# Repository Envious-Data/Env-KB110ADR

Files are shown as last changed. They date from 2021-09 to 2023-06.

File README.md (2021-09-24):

# Env-KB110ADR
A STM32F411CEU6 powered Mechanical keyboard PCB designed in KiCad

- Project Name: Env-KB110ADR
- Nickname: Victus

### About
I originally helped a friend design this but he couldnt quite figure out kicad nor had the motivation, It started out as a RP2040 powered 110% layout and then got cut down to a normal 100% and switched to a STM32F411CEU6.

It also support hotswap and ansi+iso.

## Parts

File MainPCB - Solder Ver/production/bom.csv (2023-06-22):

Designator | Footprint | Quantity | Value | LCSC Part #
C9 | 0805 | 1 | 0.1uf 0805
D_100, D_101, D_102, D_103, D_104, D_105, D_106, D_107, D_108, D_109, D_110, D_111, D_112, D_113, D_114, D_115, D_116, D_117, D_12, D_13, D_14, D_15, D_16, D_17, D_18, D_19, D_20, D_21, D_22, D_23, D_24, D_25, D_26, D_27, D_28, D_29, D_30, D_31, D_32, D_33, D_34, D_35, D_36, D_37, D_38, D_39, D_40, D_41, D_42, D_43, D_44, D_45, D_46, D_47, D_48, D_49, D_50, D_51, D_52, D_53, D_54, D_55, D_56, D_57, D_58, D_59, D_60, D_61, D_62, D_63, D_64, D_65, D_66, D_67, D_68, D_69, D_70, D_71, D_72, D_73, D_74, D_75, D_76, D_77, D_78, D_79, D_80, D_81, D_82, D_83, D_84, D_85, D_86, D_87, D_88, D_89, D_90, D_91, D_92, D_93, D_94, D_95, D_96, D_97, D_98, D_99 | D_SOD-123 | 106 | 1N4148W
H1, H10, H11, H12, H2, H3, H4, H5, H6, H7, H8, H9 | MountingHole_2.2mm_M2_Pad-Mod | 12 | MountingHole
J5 | PinHeader_1x03_P1.00mm_Vertical | 1 | Conn_01x03_Male
K_100, K_101, K_102, K_103, K_104, K_104B1, K_105, K_105B1, K_106, K_106B1, K_107, K_107B1, K_108, K_108C1, K_109, K_110, K_111, K_112, K_113, K_114, K_115, K_116, K_12, K_13, K_14, K_15, K_16, K_17, K_18, K_19, K_20, K_21, K_22, K_23, K_24, K_25, K_26, K_27, K_28, K_29, K_30, K_31, K_32, K_33, K_34, K_35, K_36, K_37, K_38, K_39, K_40, K_41, K_42, K_43, K_44, K_45, K_46, K_47, K_48, K_49, K_50, K_51, K_52, K_53, K_54, K_55, K_56, K_57, K_58, K_59, K_60, K_61, K_62, K_63, K_64, K_65, K_66, K_67, K_68, K_69, K_70, K_70B1, K_71, K_72, K_73, K_74, K_75, K_76, K_77, K_78, K_79, K_80, K_81, K_82, K_83, K_84, K_85, K_86, K_87, K_88, K_89, K_90, K_91, K_92, K_93, K_94, K_95, K_96, K_97, K_98, K_99, K_ANSI_1, K_ANSI_2, K_ANSI_3 | MXOnly-1U-NoLED | 114 | KEYSW
R5, R6 | 0805 | 2 | 5.1K 0805
R8 | 0805 | 1 | 330r 0805
SW1, SW2 | Panasonic_EVQPUL_EVQPUC | 2 | EVQP
U2 | PGA2040 | 1 | PGA2040
USB1 | USB_C_TYPE-C-31-M-14 | 1 | TYPE-C-31-M-14 | C319148
stab1, stab2, stab3, stab4, stab6, stab7, stab8, stab9 | Stabilizer_Cherry_MX_2u | 8 | MountingHole
stab101 | Stabilizer_Cherry_MX_7u | 1 | MountingHole
stab5 | Stabilizer_Cherry_MX_6.25u | 1 | MountingHole

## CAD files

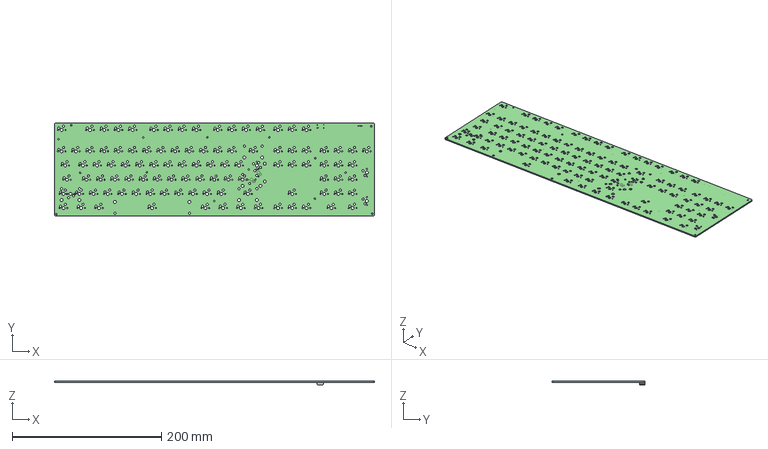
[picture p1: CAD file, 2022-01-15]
MainPCB-RP2040/EnvKB110ADR-RP2040.step
429.5 x 125.0 x 4.86 mm
EnvKB110ADR-RP2040 PCB

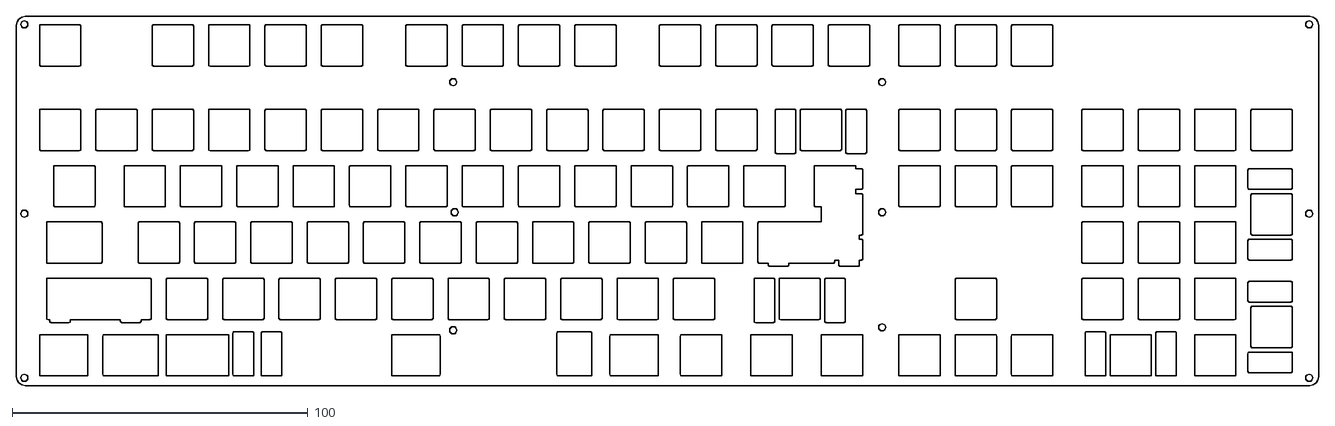
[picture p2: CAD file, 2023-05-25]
SwitchPlate/_gbr/110ADR-SwitchPlate-Edge_Cuts.dxf
440.3 x 124.8

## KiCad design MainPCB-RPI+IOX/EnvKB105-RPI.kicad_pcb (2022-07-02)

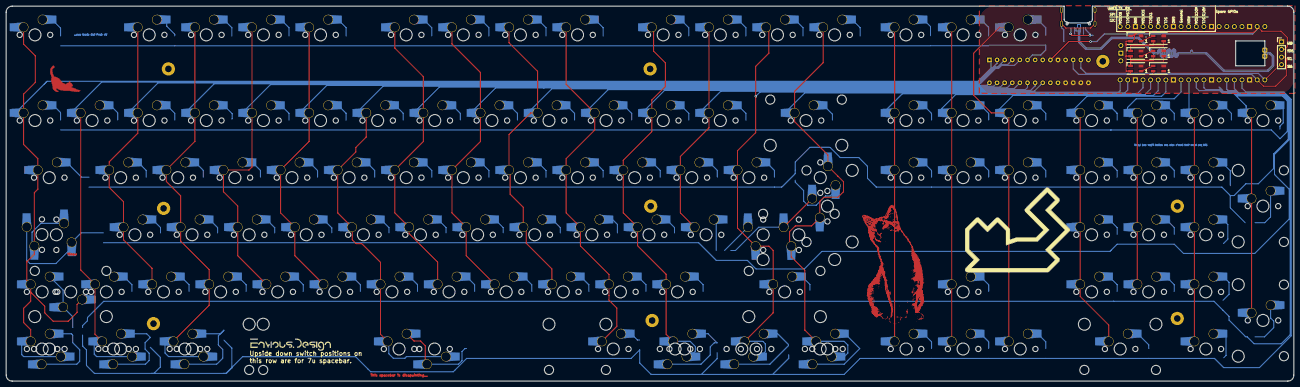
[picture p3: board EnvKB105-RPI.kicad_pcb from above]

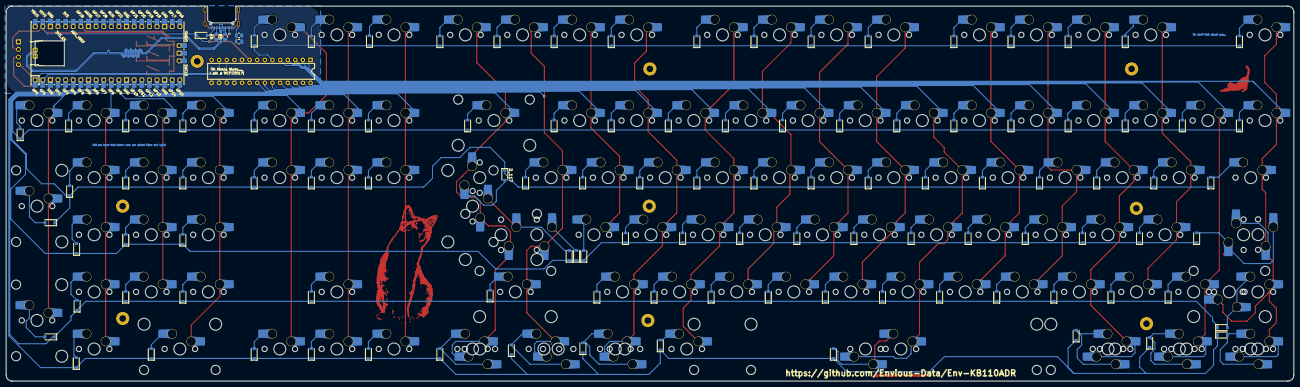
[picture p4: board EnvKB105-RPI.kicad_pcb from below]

Board: 2 copper layers, 429.5 x 125.1 mm, 257 parts (114 on the bottom side), 150 nets.

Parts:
C1: 0.1uf; C_0805_2012Metric
D1: 1N4002W; D_SOD-123
D_12, D_13, D_14, D_15, D_16, D_17, D_18, D_19, D_20, D_21, D_22, D_23, D_24, D_25, D_26, D_27, D_28, D_29, D_30, D_31, D_32, D_33, D_34, D_35, D_36, D_37, D_38, D_39, D_40, D_41, D_42, D_43, D_44, D_45, D_46, D_47, D_48, D_49, D_50, D_51, D_52, D_53, D_54, D_55, D_56, D_57, D_58, D_59, D_60, D_61, D_62, D_63, D_64, D_65, D_66, D_67, D_68, D_69, D_70, D_71, D_72, D_73, D_74, D_75, D_76, D_77, D_78, D_79, D_80, D_81, D_82, D_83, D_84, D_85, D_86, D_87, D_88, D_89, D_90, D_91, D_92, D_93, D_94, D_95, D_96, D_97, D_98, D_99, D_100, D_101, D_102, D_103, D_104, D_105, D_106, D_107, D_108, D_109, D_110, D_111, D_112, D_113, D_114, D_115, D_116, D_117: SOD-123; D_SOD-123
H1, H2, H3, H4, H5, H6, H7, H8, H9: MountingHole; MountingHole_2.2mm_M2_Pad-Mod
J1: Conn_01x04; PinHeader_1x04_P2.54mm_Vertical
K_12, K_13, K_14, K_15, K_16, K_17, K_18, K_19, K_20, K_21, K_22, K_23, K_24, K_25, K_26, K_27, K_28, K_29, K_30, K_31, K_32, K_33, K_34, K_35, K_36, K_37, K_38, K_39, K_40, K_41, K_42, K_43, K_44, K_45, K_46, K_47, K_48, K_49, K_50, K_51, K_52, K_53, K_54, K_55, K_56, K_57, K_58, K_59, K_60, K_61, K_62, K_63, K_64, K_65, K_66, K_67, K_68, K_69, K_70, K_70B1, K_71, K_72, K_73, K_74, K_75, K_76, K_77, K_78, K_79, K_80, K_81, K_82, K_83, K_84, K_85, K_86, K_87, K_88, K_89, K_90, K_91, K_92, K_93, K_94, K_95, K_96, K_97, K_98, K_99, K_100, K_101, K_102, K_103, K_104, K_104B1, K_105, K_105B1, K_106, K_106B1, K_107, K_107B1, K_108, K_108B1, K_109, K_109B1, K_110, K_111, K_111B1, K_112, K_113, K_114, K_115, K_116: KEYSW; MXOnly-1U-Hotswap-Modified
K_ANSI_1, K_ANSI_2, K_ANSI_3: KEYSW; MXOnly-1U-Hotswap-Modified
R1: 330r; R_0805_2012Metric
R5, R6: 5.1K 0402; R_0805_2012Metric
U1: Pico; RPi_Pico_SMD_TH_Modified
U2: MCP23017_SP; DIP-28_W7.62mm
USB1: TYPE-C-31-M-14; USB_C_TYPE-C-31-M-14
kibuzzard-6261CED5: G***; kibuzzard-6261CED5
rgb1, rgb2, rgb3, rgb4, rgb5, rgb6: SK6812MINI; LED_SK6812MINI_PLCC4_3.5x3.5mm_P1.75mm
stab1, stab2, stab3, stab4, stab6, stab7, stab8, stab9: MountingHole; Stabilizer_Cherry_MX_2u
stab5: MountingHole; Stabilizer_Cherry_MX_6.25u
stab101: MountingHole; Stabilizer_Cherry_MX_7u

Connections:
GND: C1.2, J1.1, R1.2, R5.1, R6.1, U1.3 (GND), U1.8 (GND), U1.13 (GND), U1.18 (GND), U1.23 (GND), U1.28 (GND), U1.33 (AGND), U1.38 (GND), U2.10 (VSS), U2.15 (A0), U2.16 (A1), U2.17 (A2), U2.18 (~RESET), USB1.A1 (GND), USB1.A12 (GND), USB1.B1 (GND), USB1.B12 (GND), rgb1.2 (VSS), rgb2.2 (VSS), rgb3.2 (VSS), rgb4.2 (VSS), rgb5.2 (VSS), rgb6.2 (VSS)
GP28-LED: U1.34 (GPIO28_ADC2), rgb1.3 (DIN)
I2C_SCL-1: J1.3, U1.2 (GPIO1), U2.12 (SCK)
I2C_SDA-1: J1.4, U1.1 (GPIO0), U2.13 (SDA)
unnamed: C1.1, R1.1, USB1.S1 (SHIELD)
unnamed: D_12.2 (A), K_12.2 (ROW)
unnamed: D_13.2 (A), K_13.2 (ROW)
unnamed: D_14.2 (A), K_14.2 (ROW)
unnamed: D_15.2 (A), K_15.2 (ROW)
unnamed: D_16.2 (A), K_16.2 (ROW)
unnamed: D_17.2 (A), K_17.2 (ROW)
unnamed: D_18.2 (A), K_18.2 (ROW)
unnamed: D_19.2 (A), K_19.2 (ROW)
unnamed: D_20.2 (A), K_20.2 (ROW)
unnamed: D_21.2 (A), K_21.2 (ROW)
unnamed: D_22.2 (A), K_22.2 (ROW)
unnamed: D_23.2 (A), K_23.2 (ROW)
unnamed: D_24.2 (A), K_24.2 (ROW)
unnamed: D_25.2 (A), K_25.2 (ROW)
unnamed: D_26.2 (A), K_26.2 (ROW)
unnamed: D_27.2 (A), K_27.2 (ROW)
unnamed: D_28.2 (A), K_28.2 (ROW)
unnamed: D_29.2 (A), K_29.2 (ROW)
unnamed: D_30.2 (A), K_30.2 (ROW)
unnamed: D_31.2 (A), K_31.2 (ROW)
unnamed: D_32.2 (A), K_32.2 (ROW)
unnamed: D_33.2 (A), K_33.2 (ROW)
unnamed: D_34.2 (A), K_34.2 (ROW)
unnamed: D_35.2 (A), K_35.2 (ROW)
unnamed: D_36.2 (A), K_36.2 (ROW)
unnamed: D_37.2 (A), K_37.2 (ROW)
unnamed: D_38.2 (A), K_38.2 (ROW)
unnamed: D_39.2 (A), K_39.2 (ROW)
unnamed: D_40.2 (A), K_40.2 (ROW)
unnamed: D_41.2 (A), K_41.2 (ROW)
unnamed: D_42.2 (A), K_42.2 (ROW)
unnamed: D_43.2 (A), K_43.2 (ROW)
unnamed: D_44.2 (A), K_44.2 (ROW)
unnamed: D_45.2 (A), K_45.2 (ROW)
unnamed: D_46.2 (A), K_46.2 (ROW)
unnamed: D_47.2 (A), K_47.2 (ROW)
unnamed: D_48.2 (A), K_48.2 (ROW)
unnamed: D_49.2 (A), K_49.2 (ROW)
unnamed: D_50.2 (A), K_50.2 (ROW)
unnamed: D_51.2 (A), K_51.2 (ROW)
unnamed: D_52.2 (A), K_52.2 (ROW)
unnamed: D_53.2 (A), K_53.2 (ROW)
unnamed: D_54.2 (A), K_54.2 (ROW)
unnamed: D_55.2 (A), K_55.2 (ROW)
unnamed: D_56.2 (A), K_56.2 (ROW)
unnamed: D_57.2 (A), K_57.2 (ROW)
unnamed: D_58.2 (A), K_58.2 (ROW)
unnamed: D_59.2 (A), K_59.2 (ROW)
unnamed: D_60.2 (A), K_60.2 (ROW)
unnamed: D_61.2 (A), K_61.2 (ROW)
unnamed: D_62.2 (A), K_62.2 (ROW), K_ANSI_2.2 (ROW)
unnamed: D_63.2 (A), K_63.2 (ROW)
unnamed: D_64.2 (A), K_64.2 (ROW)
unnamed: D_65.2 (A), K_65.2 (ROW)
unnamed: D_66.2 (A), K_66.2 (ROW)
unnamed: D_67.2 (A), K_67.2 (ROW)
unnamed: D_68.2 (A), K_68.2 (ROW)
unnamed: D_69.2 (A), K_69.2 (ROW)
unnamed: D_70.2 (A), K_70.2 (ROW), K_70B1.2 (ROW)
unnamed: D_71.2 (A), K_71.2 (ROW)
unnamed: D_72.2 (A), K_72.2 (ROW)
unnamed: D_73.2 (A), K_73.2 (ROW)
unnamed: D_74.2 (A), K_74.2 (ROW)
unnamed: D_75.2 (A), K_75.2 (ROW)
unnamed: D_76.2 (A), K_76.2 (ROW)
unnamed: D_77.2 (A), K_77.2 (ROW)
unnamed: D_78.2 (A), K_78.2 (ROW)
unnamed: D_79.2 (A), K_79.2 (ROW)
unnamed: D_80.2 (A), K_80.2 (ROW)
unnamed: D_81.2 (A), K_81.2 (ROW)
unnamed: D_82.2 (A), K_82.2 (ROW)
unnamed: D_83.2 (A), K_83.2 (ROW)
unnamed: D_84.2 (A), K_84.2 (ROW)
unnamed: D_85.2 (A), K_85.2 (ROW)
unnamed: D_86.2 (A), K_86.2 (ROW), K_ANSI_1.2 (ROW)
unnamed: D_87.2 (A), K_87.2 (ROW)
unnamed: D_88.2 (A), K_88.2 (ROW)
unnamed: D_89.2 (A), K_89.2 (ROW)
unnamed: D_90.2 (A), K_90.2 (ROW)
unnamed: D_91.2 (A), K_91.2 (ROW)
unnamed: D_92.2 (A), K_92.2 (ROW)
unnamed: D_93.2 (A), K_93.2 (ROW)
unnamed: D_94.2 (A), K_94.2 (ROW)
unnamed: D_95.2 (A), K_95.2 (ROW)
unnamed: D_96.2 (A), K_96.2 (ROW)
unnamed: D_97.2 (A), K_97.2 (ROW)
unnamed: D_98.2 (A), K_98.2 (ROW)
unnamed: D_99.2 (A), K_99.2 (ROW)
unnamed: D_100.2 (A), K_100.2 (ROW)
unnamed: D_101.2 (A), K_101.2 (ROW)
unnamed: D_102.2 (A), K_102.2 (ROW)
unnamed: D_103.2 (A), K_103.2 (ROW)
unnamed: D_104.2 (A), K_104.2 (ROW), K_104B1.2 (ROW)
unnamed: D_105.2 (A), K_105.2 (ROW), K_105B1.2 (ROW)
unnamed: D_106.2 (A), K_106.2 (ROW), K_106B1.2 (ROW)
unnamed: D_107.2 (A), K_107.2 (ROW), K_107B1.2 (ROW)
unnamed: D_108.2 (A), K_108.2 (ROW)
unnamed: D_109.2 (A), K_108B1.2 (ROW), K_109.2 (ROW)
unnamed: D_110.2 (A), K_109B1.2 (ROW), K_110.2 (ROW)
unnamed: D_111.2 (A), K_111.2 (ROW), K_111B1.2 (ROW)
unnamed: D_112.2 (A), K_112.2 (ROW)
unnamed: D_113.2 (A), K_113.2 (ROW)
unnamed: D_114.2 (A), K_114.2 (ROW)
unnamed: D_115.2 (A), K_115.2 (ROW)
unnamed: D_116.2 (A), K_116.2 (ROW)
unnamed: D_117.2 (A), K_ANSI_3.2 (ROW)
unnamed: R5.2, USB1.A5 (CC1)
unnamed: R6.2, USB1.B5 (CC2)
unnamed: rgb1.1 (DOUT), rgb2.3 (DIN)
unnamed: rgb2.1 (DOUT), rgb3.3 (DIN)
unnamed: rgb3.1 (DOUT), rgb4.3 (DIN)
unnamed: rgb4.1 (DOUT), rgb5.3 (DIN)
unnamed: rgb5.1 (DOUT), rgb6.3 (DIN)
USB_D+: U1.TP3 (USB_DP), USB1.A6 (D+), USB1.B6 (D+)
USB_D-: U1.TP2 (USB_DM), USB1.A7 (D-), USB1.B7 (D-)
VBUS: D1.2 (A), USB1.A4 (VBUS), USB1.A9 (VBUS), USB1.B4 (VBUS), USB1.B9 (VBUS)
VSYS: D1.1 (K), J1.2, U1.39 (VSYS), U2.9 (VDD), rgb1.4 (VDD), rgb2.4 (VDD), rgb3.4 (VDD), rgb4.4 (VDD), rgb5.4 (VDD), rgb6.4 (VDD)
col0: K_12.1 (COL), K_28.1 (COL), K_49.1 (COL), K_70.1 (COL), K_70B1.1 (COL), K_86.1 (COL), K_104.1 (COL), K_104B1.1 (COL), K_ANSI_1.1 (COL), U2.1 (GPB0)
col1: K_29.1 (COL), K_87.1 (COL), K_105.1 (COL), K_105B1.1 (COL), U2.2 (GPB1)
col2: K_13.1 (COL), K_30.1 (COL), K_50.1 (COL), K_71.1 (COL), K_88.1 (COL), U2.3 (GPB2)
col3: K_14.1 (COL), K_31.1 (COL), K_51.1 (COL), K_72.1 (COL), K_89.1 (COL), K_106.1 (COL), K_106B1.1 (COL), U2.4 (GPB3)
col4: K_15.1 (COL), K_32.1 (COL), K_52.1 (COL), K_73.1 (COL), K_90.1 (COL), U2.5 (GPB4)
col5: K_16.1 (COL), K_33.1 (COL), K_53.1 (COL), K_74.1 (COL), K_91.1 (COL), U2.28 (GPA7)
col6: K_34.1 (COL), K_54.1 (COL), K_75.1 (COL), K_92.1 (COL), K_107.1 (COL), K_107B1.1 (COL), U2.27 (GPA6)
col7: K_17.1 (COL), K_35.1 (COL), K_55.1 (COL), K_76.1 (COL), K_93.1 (COL), U2.26 (GPA5)
col8: K_18.1 (COL), K_36.1 (COL), K_56.1 (COL), K_77.1 (COL), K_94.1 (COL), U2.25 (GPA4)
col9: K_19.1 (COL), K_37.1 (COL), K_57.1 (COL), K_78.1 (COL), K_95.1 (COL), U2.24 (GPA3)
col10: K_20.1 (COL), K_38.1 (COL), K_58.1 (COL), K_79.1 (COL), K_96.1 (COL), K_108.1 (COL), U2.23 (GPA2)
col11: K_21.1 (COL), K_39.1 (COL), K_59.1 (COL), K_80.1 (COL), K_97.1 (COL), K_108B1.1 (COL), K_109.1 (COL), U2.22 (GPA1)
col12: K_22.1 (COL), K_40.1 (COL), K_60.1 (COL), K_81.1 (COL), U2.21 (GPA0)
col13: K_23.1 (COL), K_61.1 (COL), K_82.1 (COL), K_98.1 (COL), K_109B1.1 (COL), K_110.1 (COL), U1.20 (GPIO15)
col14: K_24.1 (COL), K_41.1 (COL), K_62.1 (COL), K_111.1 (COL), K_111B1.1 (COL), K_ANSI_2.1 (COL), K_ANSI_3.1 (COL), U1.19 (GPIO14)
col15: K_25.1 (COL), K_42.1 (COL), K_63.1 (COL), K_112.1 (COL), U1.17 (GPIO13)
col16: K_26.1 (COL), K_43.1 (COL), K_64.1 (COL), K_99.1 (COL), K_113.1 (COL), U1.16 (GPIO12)
col17: K_27.1 (COL), K_44.1 (COL), K_65.1 (COL), K_114.1 (COL), U1.15 (GPIO11)
col19: K_45.1 (COL), K_66.1 (COL), K_83.1 (COL), K_100.1 (COL), K_115.1 (COL), U1.14 (GPIO10)
col20: K_46.1 (COL), K_67.1 (COL), K_84.1 (COL), K_101.1 (COL), U1.12 (GPIO9)
col21: K_47.1 (COL), K_68.1 (COL), K_85.1 (COL), K_102.1 (COL), K_116.1 (COL), U1.11 (GPIO8)
col22: K_48.1 (COL), K_69.1 (COL), K_103.1 (COL), U1.10 (GPIO7)
row1: D_12.1 (K), D_13.1 (K), D_14.1 (K), D_15.1 (K), D_16.1 (K), D_17.1 (K), D_18.1 (K), D_19.1 (K), D_20.1 (K), D_21.1 (K), D_22.1 (K), D_23.1 (K), D_24.1 (K), D_25.1 (K), D_26.1 (K), D_27.1 (K), U2.6 (GPB5)
row3: D_28.1 (K), D_29.1 (K), D_30.1 (K), D_31.1 (K), D_32.1 (K), D_33.1 (K), D_34.1 (K), D_35.1 (K), D_36.1 (K), D_37.1 (K), D_38.1 (K), D_39.1 (K), D_40.1 (K), D_41.1 (K), D_42.1 (K), D_43.1 (K), D_44.1 (K), D_45.1 (K), D_46.1 (K), D_47.1 (K), D_48.1 (K), U1.9 (GPIO6)
row4: D_49.1 (K), D_50.1 (K), D_51.1 (K), D_52.1 (K), D_53.1 (K), D_54.1 (K), D_55.1 (K), D_56.1 (K), D_57.1 (K), D_58.1 (K), D_59.1 (K), D_60.1 (K), D_61.1 (K), D_63.1 (K), D_64.1 (K), D_65.1 (K), D_66.1 (K), D_67.1 (K), D_68.1 (K), D_69.1 (K), D_117.1 (K), U1.7 (GPIO5)
row5: D_62.1 (K), D_70.1 (K), D_71.1 (K), D_72.1 (K), D_73.1 (K), D_74.1 (K), D_75.1 (K), D_76.1 (K), D_77.1 (K), D_78.1 (K), D_79.1 (K), D_80.1 (K), D_81.1 (K), D_82.1 (K), D_83.1 (K), D_84.1 (K), D_85.1 (K), U1.6 (GPIO4)
row6: D_86.1 (K), D_87.1 (K), D_88.1 (K), D_89.1 (K), D_90.1 (K), D_91.1 (K), D_92.1 (K), D_93.1 (K), D_94.1 (K), D_95.1 (K), D_96.1 (K), D_97.1 (K), D_98.1 (K), D_99.1 (K), D_100.1 (K), D_101.1 (K), D_102.1 (K), D_103.1 (K), U1.5 (GPIO3)
row7: D_104.1 (K), D_105.1 (K), D_106.1 (K), D_107.1 (K), D_108.1 (K), D_109.1 (K), D_110.1 (K), D_111.1 (K), D_112.1 (K), D_113.1 (K), D_114.1 (K), D_115.1 (K), D_116.1 (K), U1.4 (GPIO2)

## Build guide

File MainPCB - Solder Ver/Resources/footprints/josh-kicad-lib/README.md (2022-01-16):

# josh-kicad-lib
KiCad library for all of my projects

## To Use
Create a new directory  

Initialise git  
```git init```  

Create library submodule  
``` git submodule add https://github.com/joshajohnson/josh-kicad-lib.git```  

Create a hardware directory, and copy the template folder into hardware folder  

Rename template files as required  

Ready to design your next board!

### Script to generate files
Thanks to [Silvio](https://twitter.com/silviocesare) for making `setup.sh` which automates the generation of the required files. 

From `josh-kicad-lib` run `./setup.sh version MyProject "Your Name"` which will copy the template directory to hardware/$Version and change the names of template * to MyProject, along with changing the company name of the KiCad files. 

### Folder Structure
This should result in a folder structure which looks like the below. If your KiCad project is not two levels below this library, things will not work properly.

``` 
kicad-project-git
|- .git
|
|- .gitmodules
|- hardware
|  |- version
|     |- fp-info-cache
|     |- fp-lib-table
|     |- sim-lib-table
|     |- <project>.kicad_pcb
|     |- ...
|
|- josh-kicad-lib
|  |- lib files
|
|- README.md 
```

### Addition of new libraries / 3d models
Ensure all paths use the below text at the start of the path, as this keeps everything relative and ensures that it will work across different locations and computers. 

``` ${KIPRJMOD}/../../josh-kicad-lib/...```

### Common part details used in library
`common-parts.xlsx` contains details for a bunch of the parts commonly used in this library / my designs, and can be used to make generating the bom files with MPN/DigiKey/LCSC/etc details easier.

### Thanks to the below people for use of their symbols / footprints / 3D models
* [arturo182](https://twitter.com/arturo182) for the USB Type-C Connector.

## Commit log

2021-06-15 some corrections as per DRC - 2 unconnected items
    [EnvKB110ADR.kicad_pcb]
2021-06-15 Trying to prettify traces (Abysmal job of it)
    [EnvKB110ADR.kicad_pcb]
2021-06-16 Corrected some errors and fixed the enter key traces
    [EnvKB110ADR.kicad_pcb]
2021-06-16 setup some board bits
    [EnvKB110ADR.kicad_pcb, EnvKB110ADR.sch]
2021-06-16 Removed some overlapping and pointless traces.
    [EnvKB110ADR.kicad_pcb]
2021-06-17 Modified Kicad Projects to make generating DXFs for laser cutting easier.
    [BackPCB.kicad_pcb, BackPlate.dxf, SwitchPlate.dxf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]
2021-06-20 Made some tweaks to allow for easier Gerber generation
    [BackPCB.kicad_pcb, BackPlate.dxf, SwitchPlate.dxf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]
2021-07-04 Started work on swapping RPI pico for STM32F411CEU6
    [EnvKB110ADR.kicad_pcb, EnvKB110ADR.sch]
2021-07-04 added some notes in the schematic
    [EnvKB110ADR.sch]
2021-07-04 hopefully correct implementation of a 8mhz oscilator
    [EnvKB110ADR.sch]
2021-07-05 added boot and reset switches
    [EnvKB110ADR.sch]
2021-07-05 added decoupling capacitors for LDO
    [EnvKB110ADR.sch]
2021-07-05 annotated parts + notes adjustment
    [EnvKB110ADR.sch]
2021-07-05 Updated PCB to have new parts
    [EnvKB110ADR.kicad_pcb]
2021-07-10 Added row/col pins in the schematic for pcbnew to show them
    [EnvKB110ADR.kicad_pcb, EnvKB110ADR.sch]
2021-09-21 See List
    - Added ANSI support
    - redone sections of the board to fit ansi support
    - edited all footprints to have through holes so they can be connected on both sides.
    - probably a bunch of other shite
    [EnvKB110ADR.kicad_pcb, EnvKB110ADR.sch]
2021-09-21 more progress, working on column traces.
    [EnvKB110ADR.kicad_pcb, EnvKB110ADR.sch]
2021-09-21 finished up traces and added a cat silkscreen.
    [EnvKB110ADR.kicad_pcb, EnvKB110ADR.sch]
2021-09-24 Corrected a trace going through a hole
    [EnvKB110ADR.kicad_pcb]
2021-09-24 removed incorrect backplate and switch plate, I will re-make this in the future once the main PCB is a bit closer to being finished.
    [BackPCB.kicad_pcb, BackPCB.sch, SwitchPlate.kicad_pcb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]
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2021-09-24 changed oscillator for crystal, re-added libraries, made change in PCBNew
    [EnvKB110ADR.kicad_pcb, EnvKB110ADR.sch]
2021-09-28 Small fixes and corrections
    [EnvKB110ADR.kicad_pcb, EnvKB110ADR.sch]
2021-09-28 some general changes, might change MCU to RP2040
    [EnvKB110ADR.kicad_pcb, EnvKB110ADR.sch]
2021-09-28 Converted board from STM32F411CEU6 to RP2040
    [EnvKB110ADR.kicad_pcb, EnvKB110ADR.sch]
2021-09-28 wired up all the traces required to make the keyboard functional.
    However this means you can no longer use the Rpi pico firmware with this and needs a custom compiled firmware to utilize the normally unavailable pins,
    [EnvKB110ADR.kicad_pcb, EnvKB110ADR.sch]
2021-09-28 Generated updated gerbers
    [EnvKB110ADR.kicad_pcb, EnvKB110ADR_bom_jlc.csv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]
2021-09-28 Replaced flash with smaller uson-8 3x2 + regenerated Gerbers
    [EnvKB110ADR.kicad_pcb, EnvKB110ADR.sch, EnvKB110ADR_bom_jlc.csv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]
2021-09-28 corrected small issue and updated gerber again
    [EnvKB110ADR.kicad_pcb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]
2021-09-28 Decided to retain STM32F411CEU6 version and also made symlink for shared resources
    [EnvKB110ADR-RP2040.kicad_pcb, EnvKB110ADR-RP2040.sch, EnvKB110ADR-STM32.kicad_pcb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]
2021-09-28 Flipped STM32 to other side of board and added a debug header (SWDIO/SWCLK)
    [EnvKB110ADR-STM32.kicad_pcb, EnvKB110ADR-STM32.sch]
2021-09-30 added mount holes, fixed a couple trace errors, created backplate PCB
    [110ADR-BackPCB.kicad_pcb, 110ADR-BackPCB.sch, EnvKB110ADR-RP2040.kicad_pcb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]
2021-09-30 Created switch plate
    [110ADR-SwitchPlate.kicad_pcb, 110ADR-SwitchPlate.sch, EnvKB110ADR-RP2040.kicad_pcb]
2021-09-30 padded switch plate and generated gerber for test price (£19.43)
    [110ADR-SwitchPlate-B_Cu.gbl, 110ADR-SwitchPlate-B_Mask.gbs, 110ADR-SwitchPlate-B_Paste.gbp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]
2021-09-30 forgot to commit this change lol.
    [110ADR-SwitchPlate.kicad_pcb]
2021-10-02 comitted some changes made
    [EnvKB110ADR-RP2040.kicad_pcb]
2021-10-22 small corrections and mild cleanup
    [EnvKB110ADR-RP2040.kicad_pcb]
2021-10-22 generated updated Gerber for RP2040 Version
    [EnvKB110ADR-RP2040.kicad_pcb]
2021-10-26 cleaned a couple derps up.
    [EnvKB110ADR-RP2040.kicad_pcb]
2021-10-28 corrections to design, via in pad and such
    [EnvKB110ADR-RP2040.kicad_pcb, EnvKB110ADR-RP2040.sch]
2021-11-19 added logo for black cat plastic works, couple urls and some fixes to design
    [EnvKB110ADR-RP2040.kicad_pcb, EnvKB110ADR-RP2040.sch]
2021-11-19 moved site name up a bit
    [EnvKB110ADR-RP2040.kicad_pcb]
2021-11-21 general corrections and tweaks
    [EnvKB110ADR-RP2040.kicad_pcb]
2021-11-25 replaced switch footprints with stronger versions and SMT assembly compatible versions
    [EnvKB110ADR-RP2040.kicad_pcb, EnvKB110ADR-RP2040.sch]
2021-11-30 general adjustments, fixes and tweaks on STM32 version
    [EnvKB110ADR-STM32.kicad_pcb, EnvKB110ADR-STM32.sch]
2021-11-30 Corrected inverted traces I think.
    [EnvKB110ADR-STM32.kicad_pcb]
2021-11-30 added missing capacitor on vcap
    [EnvKB110ADR-STM32.kicad_pcb, EnvKB110ADR-STM32.sch]
2021-11-30 added missing capacitor and power connection
    [EnvKB110ADR-STM32.kicad_pcb, EnvKB110ADR-STM32.sch]
2021-12-05 Generated updated Gerber
    [EnvKB110ADR-RP2040.kicad_pcb, EnvKB110ADR-STM32.kicad_pcb]
2022-01-11 fixed a random trace that was left over from something else.
    [EnvKB110ADR-RP2040.kicad_pcb]
2022-01-15 updated PCB to fit stocked JLC Parts and added BOM and CPL to .gitignore
    [EnvKB110ADR-RP2040.kicad_sch, EnvKB110ADR-RP2040_bom_jlc.csv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]
2022-01-15 added missing stabilizers and updated gerber
    [EnvKB110ADR-RP2040.kicad_sch, EnvKB110ADR-RP2040.step, EnvKB110ADR-RP2040_bom_jlc.csv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]
2022-01-16 some corrections and adjustments regarding 3.3v decoupling capacitors.
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2022-01-16 swapped port for mid-mount version
    [EnvKB110ADR-RP2040.kicad_sch, template.kicad_pcb, template.sch]
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2022-01-18 updated gerber again and exported some layers and what not.
    [EnvKB110ADR-RP2040-Edge_Cuts.dxf, EnvKB110ADR-RP2040-User_Eco1.dxf, EnvKB110ADR-RP2040-User_Eco2.dxf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]
2022-01-27 Added part number for the nor flash and also changed footprint to correct one? also added some smol easter eggs.
    [EnvKB110ADR-RP2040.kicad_sch]
2022-04-17 various improvements/ made ISO only (for now maybe)
    [EnvKB110ADR-RP2040.kicad_sch]
2022-04-21 properly implemented ANSI/ISO support.
    [EnvKB110ADR-RP2040.kicad_sch]
2022-04-21 various updates and adjustments
    [EnvKB110ADR-RP2040.kicad_pcb, EnvKB110ADR-RP2040.kicad_sch]
2022-04-22 Generated Gerber to check price
    [EnvKB110ADR-RP2040-Edge_Cuts.dxf, EnvKB110ADR-RP2040-User_Eco1.dxf, EnvKB110ADR-RP2040-User_Eco2.dxf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]
2022-06-07 made version with rpi pico and io expander
    [EnvKB105-RPI.kicad_pcb, EnvKB105-RPI.kicad_sch]
2022-06-07 moved some 3d models locally
    [EnvKB105-RPI.kicad_pcb]
2022-06-07 generated gerber, bom and cpl
    [EnvKB105-RPI.kicad_pcb]
2022-06-07 fixed ref and generated updated gerber
    [EnvKB105-RPI.kicad_pcb, EnvKB105-RPI.kicad_sch]
2022-06-07 changed switch plates to fit thicker materials
    [EnvKB105-RPI.kicad_pcb]
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2022-06-11 swapped IO expander package to DIP
    [EnvKB105-RPI.kicad_pcb, EnvKB105-RPI.kicad_sch]
2022-06-11 Added position for OLED and RGB indicator LEDs among other things
    [EnvKB105-RPI.kicad_pcb, EnvKB105-RPI.kicad_sch]
2022-06-11 some adjustments to make CAD a bit easier
    [EnvKB105-RPI.kicad_pcb, EnvKB105-RPI.kicad_sch]
2022-06-11 Changed my mind on Mount holes
    [EnvKB105-RPI.kicad_pcb, EnvKB105-RPI.kicad_sch]
2022-06-24 added 7u bottom and stepped capslock
    [EnvKB105-RPI.kicad_pcb, EnvKB105-RPI.kicad_sch]
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2022-12-01 some general tweaks and preparation for ordering
    [EnvKB105-RPI.kicad_sch]
2023-05-25 removed variants in favor of RP2040 version with no IO expander, needs finishing up
    [EnvKB105-RPI.kicad_sch, EnvKB110ADR-RP2040.kicad_pcb, EnvKB110ADR-RP2040.kicad_sch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]
2023-05-25 Various fixes to clearances and fixed a lot of traces
    [110ADR-BackPCB.kicad_pcb, 110ADR-SwitchPlate.kicad_pcb, EnvKB105-RPI.kicad_sch]
2023-05-25 Made solder version and fixed up all its issues
    [EnvKB105-RPI.kicad_sch, template.kicad_pcb, template.sch]
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2023-05-25 generated Gerbers for solder version
    [EnvKB105-RPI.kicad_sch, bom.csv, designators.csv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]
2023-05-25 generated files to be used to model case
    [110ADR-SwitchPlate-Edge_Cuts.dxf, 110ADR-SwitchPlate.kicad_pcb]
2023-06-22 cleanup and swapped MCU to PGA2040 on solder version as experiment.
    [110ADR-BackPCB.kicad_pcb, EnvKB105-RPI.kicad_sch, bom.csv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]
2023-06-22 swapped buttons to Panasonic side buttons and wired up debug header
    [EnvKB105-RPI.kicad_sch]
2023-06-22 some small fixes and adjustments to mount holes
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2024-04-29 replaced PGA2040 with STM32F401
    [EnvKB105-RPI.kicad_sch, EnvKB105.kicad_sch]
2024-04-29 tweaked a couple connections to avoid problems
    [EnvKB105.kicad_sch]
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
